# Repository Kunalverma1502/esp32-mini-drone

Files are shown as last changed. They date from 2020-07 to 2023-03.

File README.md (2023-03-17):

# ESP-32 Drone 🛸
ESP-32 Drone is an open-source light weight and compact drone with extended IO's for adding multiple sensors.

# Hardware ⚙️

## Designs

### 3D CAD
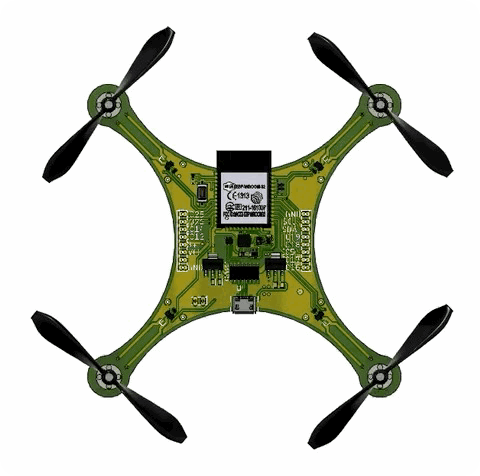
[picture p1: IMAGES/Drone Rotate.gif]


## Features

 - 
 - 
 - 
 - 
 - 
 <br/>
  <br/>
   <br/>
    <br/>
     <br/>
  <br/>
   <br/>
    <br/>
     <br/>
  <br/>
   <br/>
    <br/>
     <br/>
  <br/>
   <br/>
    <br/>

<p align="right">
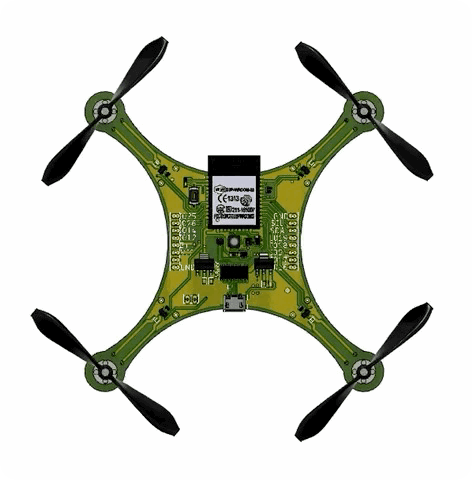
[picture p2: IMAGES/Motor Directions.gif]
  
</p>

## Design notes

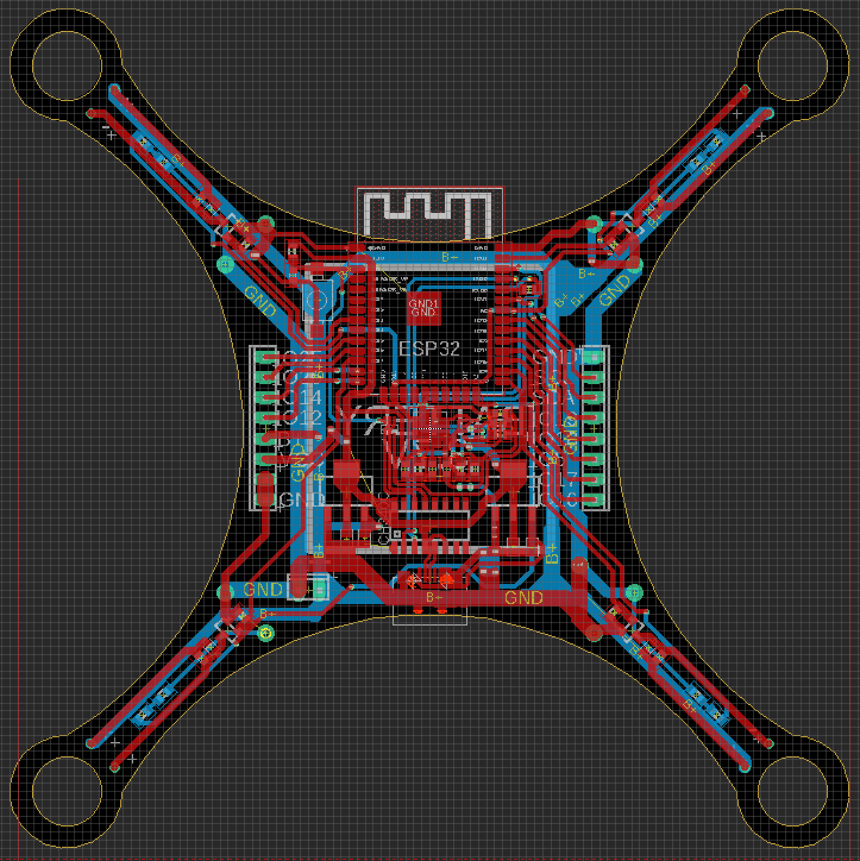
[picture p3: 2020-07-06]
SCHEMATIC/PCB VIEW.png

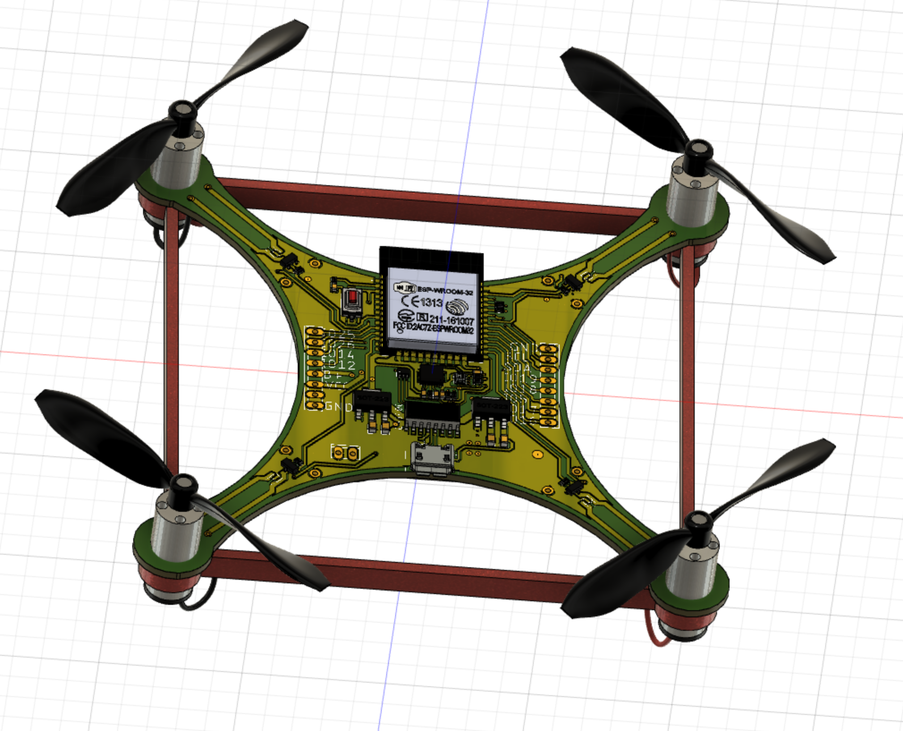
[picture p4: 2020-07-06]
CAD MODEL/IMAGES/DRONE1.png

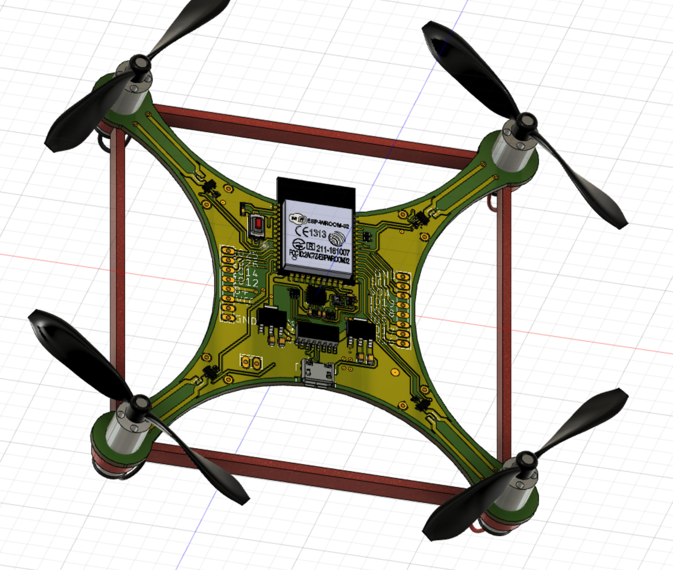
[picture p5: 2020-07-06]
CAD MODEL/IMAGES/DRONE2.png

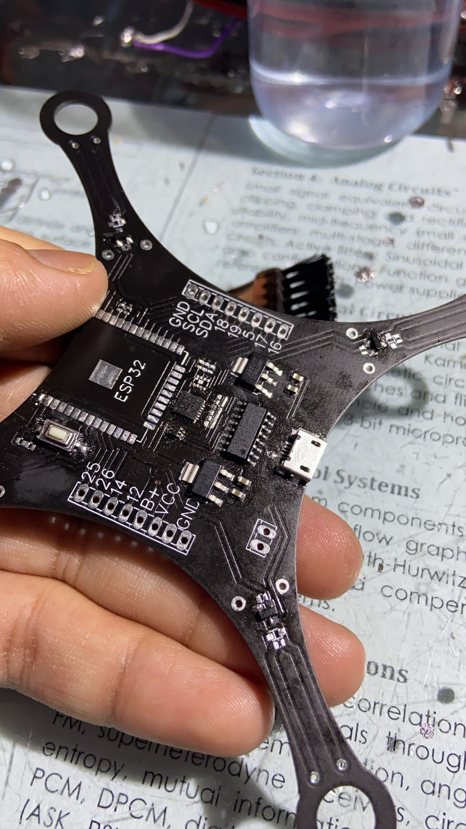
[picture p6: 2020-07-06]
IMAGES/31043101-7F11-4E39-B8AF-DA0E64A641B5.JPG

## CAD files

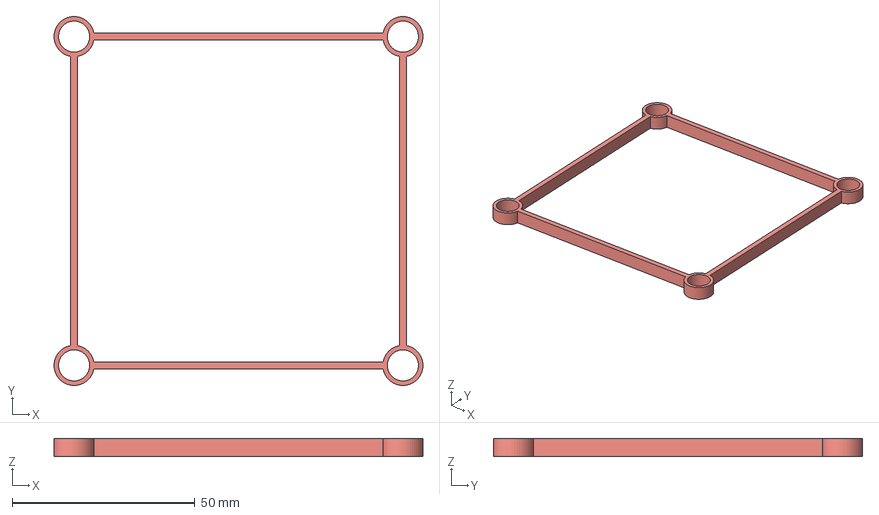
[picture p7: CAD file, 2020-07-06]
Drone Frame/DRONE_FRAME.step
101.0 x 101.0 x 5.00 mm

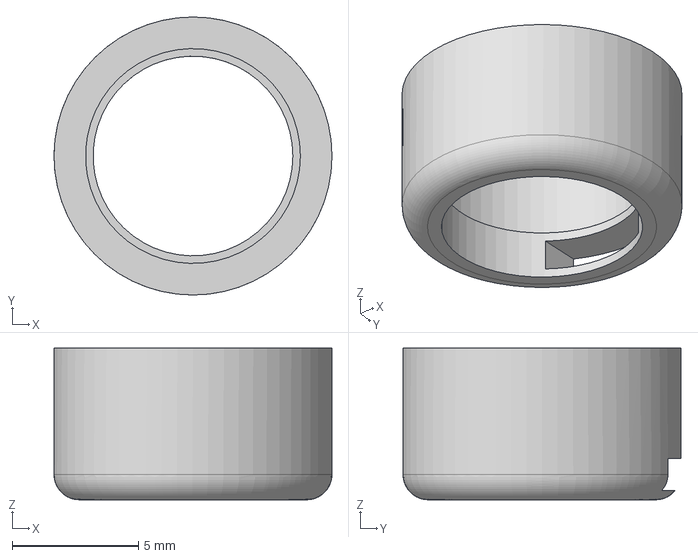
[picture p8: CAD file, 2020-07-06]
Motor Cover/MOTOR_COVER.step
11.0 x 11.0 x 6.00 mm

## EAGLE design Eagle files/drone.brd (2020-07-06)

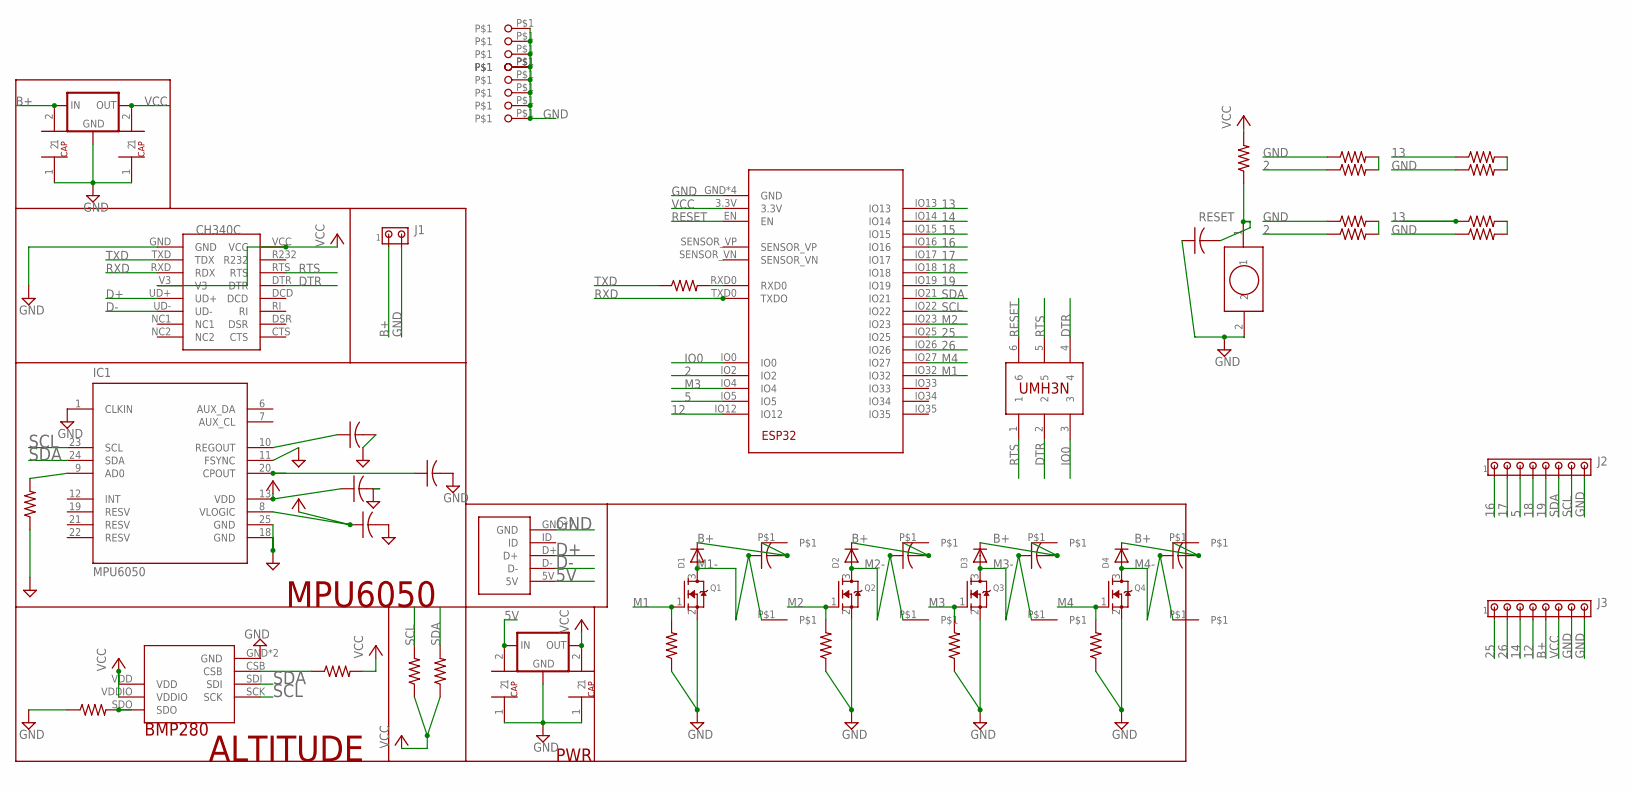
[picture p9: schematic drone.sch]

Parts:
D1, D2, D3, D4: DIODESOD-323F; SOD-323F
IC1: MPU6050; QFN50P400X400X95-25T265X275N
IC2, IC3: SELF_VREG3.3MP; SOT223
J1: MTA02-100; 10X02MTA
J2, J3: MTA08-100; 10X08MTA
Q1, Q2, Q3, Q4: MOSFET-NREFLOW; SOT23
U1: ESP32; MODULE_ESP-WROOM-32
U$1: MICROUSB; USB
U$2: CH340C; SOIC16
U$3: BMP280
U$4, U$5, U$7, U$11, U$12, U$16, U$20, U$21, U$22, U$23, U$30, U$32, U$33, U$34, U$35, U$36, U$37, U$38, U$39: R-US_R0603; R0603
U$6, U$8, U$9, U$10, U$24, U$25, U$26, U$27, U$31: C-USC0603; C0603
U$13, U$14, U$18, U$19: SELF_CAP_0603SELF_CAP_0805; SELF_CAP_0805
U$28: UMH3N
U$29: SELF_PUSHBUTTON
U$40, U$41, U$42, U$43, U$44, U$45, U$46, U$47: SELF_PINOUTS; PINOUTS
U$48, U$49, U$50, U$51, U$52, U$53, U$54, U$55, U$56: SELF_PIN2; PIN2

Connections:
2: U1.IO2, U$33.1, U$39.1
5: J2.3, U1.IO5
5V: IC2.VIN (IN), U$1.5V, U$13.2
12: J3.4, U1.IO12
13: U1.IO13, U$34.1, U$36.1
14: J3.3, U1.IO14
15: U1.IO15
16: J2.1, U1.IO16
17: J2.2, U1.IO17
18: J2.4, U1.IO18
19: J2.5, U1.IO19
25: J3.1, U1.IO25
26: J3.2, U1.IO26
B+: D1.C, D2.C, D3.C, D4.C, IC3.VIN (IN), J1.1, J3.5, U$19.2, U$24.2, U$25.2, U$26.2, U$27.2, U$40.P$1, U$42.P$1, U$44.P$1, U$46.P$1
D+: U$1.D+, U$2.UD+
D-: U$1.D-, U$2.UD-
DTR: U$2.DTR, U$28.2, U$28.4
GND: IC1.1 (CLKIN), IC1.11 (FSYNC), IC1.18 (GND), IC1.25 (GND), IC2.GND, IC3.GND, J1.2, J2.8, J3.7, J3.8, Q1.2 (S), Q2.2 (S), Q3.2 (S), Q4.2 (S), U1.GND, U1.GND1 (GND), U1.GND2 (GND), U1.GND3 (GND), U$1.GND, U$1.GND1 (GND), U$1.GND2 (GND), U$1.GND3 (GND), U$1.GND4 (GND), U$1.GND5 (GND), U$1.GND6 (GND), U$2.GND, U$3.GND, U$3.GND1 (GND), U$5.1, U$6.2, U$7.1, U$8.2, U$9.2, U$10.2, U$13.1, U$14.1, U$18.1, U$19.1, U$20.1, U$21.1, U$22.1, U$23.1, U$29.2, U$31.1, U$32.1, U$35.1, U$37.1, U$38.1, U$48.P$1, U$49.P$1, U$50.P$1, U$51.P$1, U$52.P$1, U$53.P$1, U$54.P$1, U$55.P$1, U$56.P$1
IO0: U1.IO0, U$28.3
M1: Q1.1 (G), U1.IO32, U$20.2
M1-: D1.A, Q1.3 (D), U$24.1, U$41.P$1
M2: Q2.1 (G), U1.IO23, U$21.2
M2-: D2.A, Q2.3 (D), U$26.1, U$43.P$1
M3: Q3.1 (G), U1.IO4, U$22.2
M3-: D3.A, Q3.3 (D), U$27.1, U$45.P$1
M4: Q4.1 (G), U1.IO27, U$23.2
M4-: D4.A, Q4.3 (D), U$25.1, U$47.P$1
unnamed: U$32.2, U$33.2
unnamed: U$38.2, U$39.2
unnamed: U$34.2, U$35.2
unnamed: U$36.2, U$37.2
unnamed: U$3.SDO, U$5.2
unnamed: U$3.CSB, U$4.1
unnamed: IC1.9 (AD0), U$7.2
unnamed: IC1.10 (REGOUT), U$8.1
unnamed: IC1.20 (CPOUT), U$10.1
unnamed: U1.RXD0, U$16.2
RESET: U1.EN, U$28.6, U$29.1, U$30.1, U$31.2
RTS: U$2.RTS, U$28.1, U$28.5
RXD: U1.TXD0 (TXDO), U$2.RXD (RDX)
SCL: IC1.23 (SCL), J2.7, U1.IO22, U$3.SCK, U$11.2
SDA: IC1.24 (SDA), J2.6, U1.IO21, U$3.SDI, U$12.2
TXD: U$2.TXD (TDX), U$16.1
VCC: IC1.8 (VLOGIC), IC1.13 (VDD), IC2.VOUT (OUT), IC2.VOUT1 (OUT), IC3.VOUT (OUT), IC3.VOUT1 (OUT), J3.6, U1.3.3V, U$2.V3, U$2.VCC, U$3.VDD, U$3.VDDIO, U$4.2, U$6.1, U$9.1, U$11.1, U$12.1, U$14.2, U$18.2, U$30.2

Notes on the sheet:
ALTITUDE
MPU6050
PWR

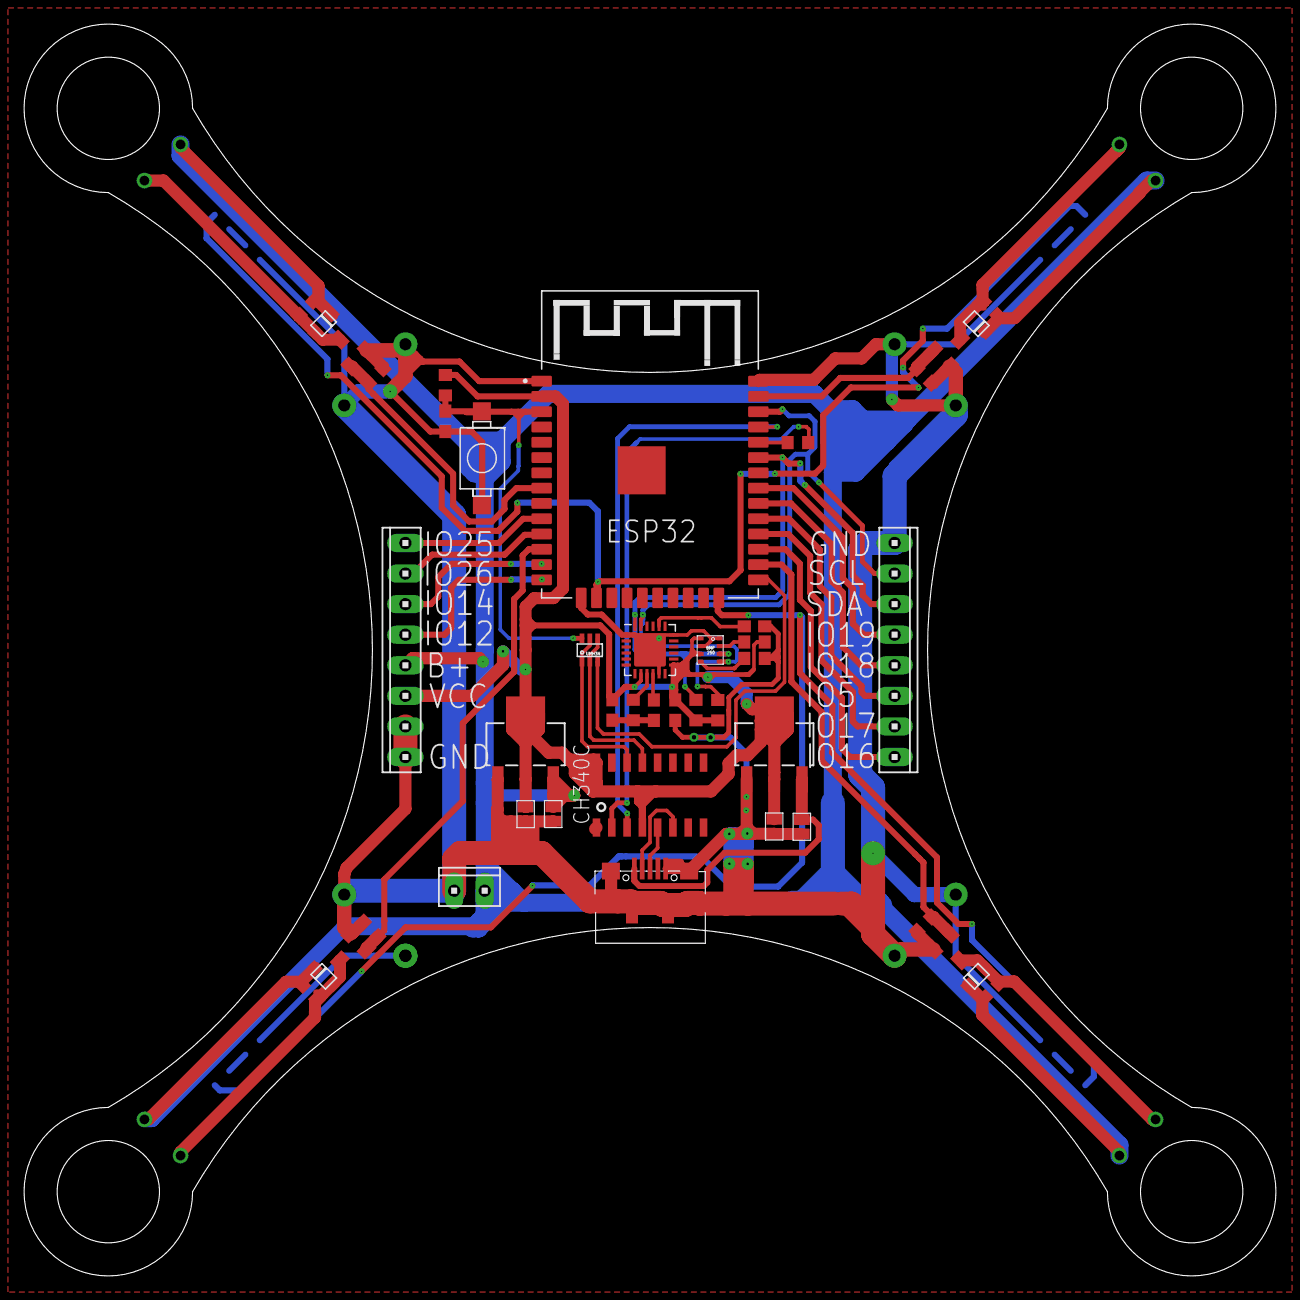
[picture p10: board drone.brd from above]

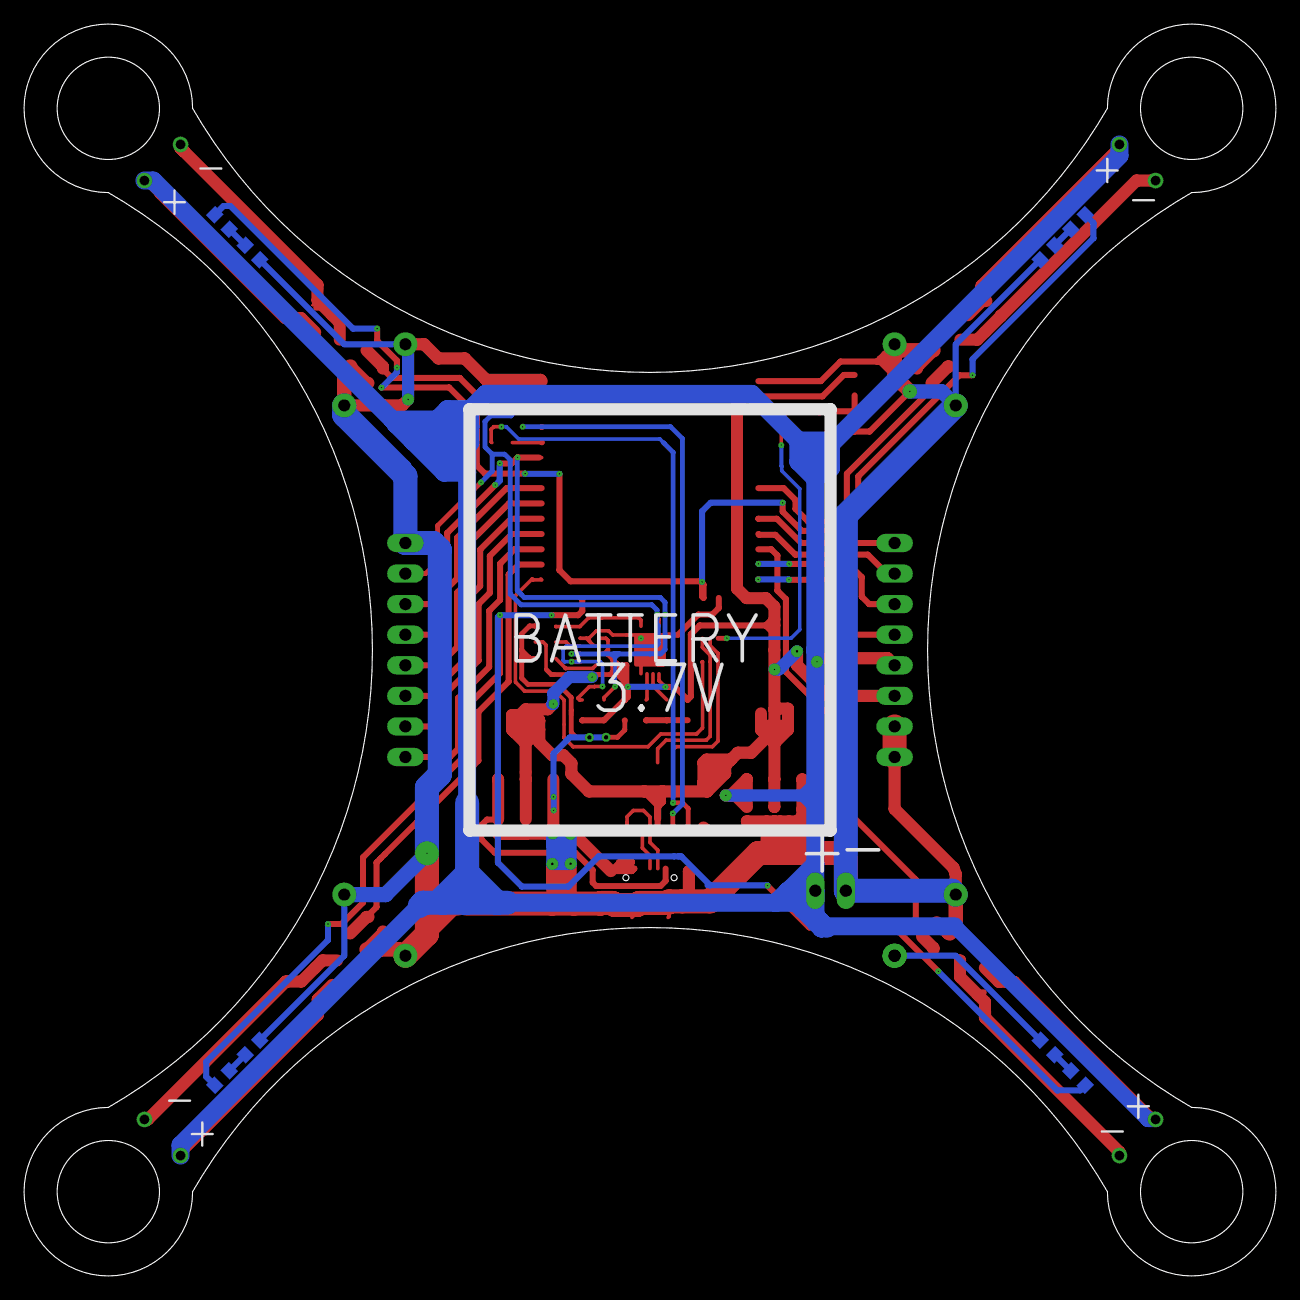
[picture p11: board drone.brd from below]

Board: 2 copper layers, 104.0 x 104.0 mm, 69 parts (8 on the bottom side), 43 nets.

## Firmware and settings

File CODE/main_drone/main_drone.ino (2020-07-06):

#include "PS3.h"
#include "MPU6050.h"



float roll_sample_angle = 0.0, pitch_sample_angle = 0.0, yaw_sample_angle = 0.0;
float roll_angle = 0.0, pitch_angle = 0.0, yaw_angle = 0.0;

float roll_sample_gyro = 0.0, pitch_sample_gyro = 0.0, yaw_sample_gyro = 0.0;
float roll_gyro = 0.0, pitch_gyro = 0.0, yaw_gyro = 0.0;


float esc_1, esc_2, esc_3, esc_4;
int throttle = 127;
int roll = 127;
int pitch = 127;
int yaw = 127;
bool drone = false;


float angle_roll_input = 0, angle_pitch_input = 0, angle_yaw_input = 0;
float pid_error_temp;
float pid_i_mem_roll, pid_roll_setpoint = 0, gyro_roll_input, pid_output_roll, pid_last_roll_d_error;
float pid_i_mem_pitch, pid_pitch_setpoint = 0, gyro_pitch_input, pid_output_pitch, pid_last_pitch_d_error;
float pid_i_mem_yaw, pid_yaw_setpoint = 0, gyro_yaw_input, pid_output_yaw, pid_last_yaw_d_error;

///////////////////////////////////////////////////////////////////////////////////////////////////////////////////////////////////////
//PID gain and limit settings
///////////////////////////////////////////////////////////////////////////////////////////////////////////////////////////////////////

float pid_p_gain_roll = 0.15;               //Gain setting for the roll P-controller
float pid_i_gain_roll = 0;              //Gain setting for the roll I-controller
float pid_d_gain_roll =  0;              //Gain setting for the roll D-controller
int pid_max_roll = 50;                    //Maximum output of the PID-controller (+/-)

float pid_p_gain_pitch = 0.2;  //Gain setting for the pitch P-controller.
float pid_i_gain_pitch = pid_i_gain_roll;  //Gain setting for the pitch I-controller.
float pid_d_gain_pitch = pid_d_gain_roll;  //Gain setting for the pitch D-controller.
int pid_max_pitch = pid_max_roll;          //Maximum output of the PID-controller (+/-)

float pid_p_gain_yaw = 0.2;                //Gain setting for the pitch P-controller. //4.0
float pid_i_gain_yaw = 0;               //Gain setting for the pitch I-controller. //0.02
float pid_d_gain_yaw = 0;                //Gain setting for the pitch D-controller.
int pid_max_yaw = 50;                     //Maximum output of the PID-controller (+/-)



void setup() {


  Serial.begin(115200);
  PS3_SETUP();
  MPU6050_SETUP();

  lights(1);

  for (int x = 0; x < 2000; x++) {
    mpu6050.update();
    roll_sample_angle +=  mpu6050.getAngleY();
    pitch_sample_angle +=  mpu6050.getAngleX();
    yaw_sample_angle += (mpu6050.getAngleZ() * -1);


    roll_sample_gyro +=  mpu6050.getGyroY();
    pitch_sample_gyro +=  mpu6050.getGyroX();
    yaw_sample_gyro +=  (mpu6050.getGyroZ() * -1);

  }

  roll_sample_angle /=  2000;
  pitch_sample_angle /= 2000;
  yaw_sample_angle /= 2000;

  roll_sample_gyro /=  2000;
  pitch_sample_gyro /=  2000;
  yaw_sample_gyro /=  2000;

  lights(0);

  Serial.println("MPU6050 calibrated");

//    Serial.println();
//  Serial.println();
//  delay(1000);
//
//  Serial.print(roll_sample_angle);
//  Serial.print("\t");
//  Serial.print(pitch_sample_angle);
//  Serial.print("\t");
//  Serial.println(yaw_sample_angle);
//  Serial.println();
//  Serial.println();
//  delay(1000);
//  
//
//  Serial.print(roll_sample_gyro);
//  Serial.print("\t");
//  Serial.print(pitch_sample_gyro);
//  Serial.print("\t");
//  Serial.println(yaw_sample_gyro);
//  delay(5000);
  

}
void calculate_pid() {
  //Roll calculations
  pid_error_temp = gyro_roll_input - pid_roll_setpoint;
  pid_i_mem_roll += pid_i_gain_roll * pid_error_temp;
  if (pid_i_mem_roll > pid_max_roll)pid_i_mem_roll = pid_max_roll;
  else if (pid_i_mem_roll < pid_max_roll * -1)pid_i_mem_roll = pid_max_roll * -1;

  pid_output_roll = pid_p_gain_roll * pid_error_temp + pid_i_mem_roll + pid_d_gain_roll * (pid_error_temp - pid_last_roll_d_error);
  if (pid_output_roll > pid_max_roll)pid_output_roll = pid_max_roll;
  else if (pid_output_roll < pid_max_roll * -1)pid_output_roll = pid_max_roll * -1;

  pid_last_roll_d_error = pid_error_temp;

  //Pitch calculations
  pid_error_temp = gyro_pitch_input - pid_pitch_setpoint;
  pid_i_mem_pitch += pid_i_gain_pitch * pid_error_temp;
  if (pid_i_mem_pitch > pid_max_pitch)pid_i_mem_pitch = pid_max_pitch;
  else if (pid_i_mem_pitch < pid_max_pitch * -1)pid_i_mem_pitch = pid_max_pitch * -1;

  pid_output_pitch = pid_p_gain_pitch * pid_error_temp + pid_i_mem_pitch + pid_d_gain_pitch * (pid_error_temp - pid_last_pitch_d_error);
  if (pid_output_pitch > pid_max_pitch)pid_output_pitch = pid_max_pitch;
  else if (pid_output_pitch < pid_max_pitch * -1)pid_output_pitch = pid_max_pitch * -1;

  pid_last_pitch_d_error = pid_error_temp;

  //Yaw calculations
  pid_error_temp = gyro_yaw_input - pid_yaw_setpoint;
  pid_i_mem_yaw += pid_i_gain_yaw * pid_error_temp;
  if (pid_i_mem_yaw > pid_max_yaw)pid_i_mem_yaw = pid_max_yaw;
  else if (pid_i_mem_yaw < pid_max_yaw * -1)pid_i_mem_yaw = pid_max_yaw * -1;

  pid_output_yaw = pid_p_gain_yaw * pid_error_temp + pid_i_mem_yaw + pid_d_gain_yaw * (pid_error_temp - pid_last_yaw_d_error);
  if (pid_output_yaw > pid_max_yaw)pid_output_yaw = pid_max_yaw;
  else if (pid_output_yaw < pid_max_yaw * -1)pid_output_yaw = pid_max_yaw * -1;

  pid_last_yaw_d_error = pid_error_temp;
}

void loop() {

  ///////////////////////////////////////////////////////////////////////////////////////////////////////////////////////////////////////
  //ANGLE & GYRO INPUTS
  ///////////////////////////////////////////////////////////////////////////////////////////////////////////////////////////////////////

  mpu6050.update();

  roll_angle = mpu6050.getAngleY() - roll_sample_angle;
  pitch_angle = mpu6050.getAngleX() - pitch_sample_angle;
  yaw_angle = (mpu6050.getAngleZ() * -1) - yaw_sample_angle;

  roll_gyro =  mpu6050.getGyroY() - roll_sample_gyro;
  pitch_gyro =  mpu6050.getGyroX() - pitch_sample_gyro;
  yaw_gyro =  (mpu6050.getGyroZ() * -1) - yaw_sample_gyro;

  ///////////////////////////////////////////////////////////////////////////////////////////////////////////////////////////////////////
  //COMPLIMENTARY FILTER 100 = 70(of previous value) + 30(of updated value)
  ///////////////////////////////////////////////////////////////////////////////////////////////////////////////////////////////////////

  angle_roll_input = (angle_roll_input * 0.94) + ((roll_angle) * 0.06);     //roll angle
  angle_pitch_input = (angle_pitch_input * 0.94) + ((pitch_angle) * 0.06);  //pitch angle
  angle_yaw_input = (angle_yaw_input * 0.94) + ((yaw_angle) * 0.06);        //yaw angle

  gyro_roll_input = (gyro_roll_input * 0.7) + ((roll_gyro) * 0.3)  ;     //roll gyro
  gyro_pitch_input = (gyro_pitch_input * 0.7) + ((pitch_gyro) * 0.3);    //pitch gyro
  gyro_yaw_input = (gyro_yaw_input * 0.7) + ((yaw_gyro) * 0.3);          //yaw gyro



  ///////////////////////////////////////////////////////////////////////////////////////////////////////////////////////////////////////
  //PS3 INPUTS
  ///////////////////////////////////////////////////////////////////////////////////////////////////////////////////////////////////////

  throttle = Ps3.data.analog.stick.ly;
  throttle = map(throttle, 127, -128, 0, 255);

  pid_roll_setpoint = 0;
  roll = Ps3.data.analog.stick.rx;
  pid_roll_setpoint = map(roll, 127, -128, 80, -80);
  pid_roll_setpoint -= angle_roll_input;
  pid_roll_setpoint /= 2;



  pid_pitch_setpoint = 0;
  pitch = Ps3.data.analog.stick.ry;
  pid_pitch_setpoint = map(pitch, 127, -128, 80, -80);
  pid_pitch_setpoint -= angle_pitch_input;
  pid_pitch_setpoint /= 2;

  pid_yaw_setpoint = 0;
  pid_yaw_setpoint -= angle_yaw_input;
  pid_yaw_setpoint /= 3.0;

  //  Serial.println(pid_roll_setpoint);
  //  Serial.print("\t");
  //  Serial.println(pid_pitch_setpoint);
  //  Serial.print("\t");
  //  Serial.println(pid_yaw_setpoint);

  //  Serial.print(gyro_roll_input);
  //  Serial.print("\t");
  //  Serial.print(gyro_pitch_input);
  //  Serial.print("\t");
  //  Serial.println(gyro_yaw_input);




  if ( Ps3.data.button.cross)
  { drone = true;


    //Reset the PID controllers for a bumpless start.
    pid_i_mem_roll = 0;
    pid_last_roll_d_error = 0;
    pid_i_mem_pitch = 0;
    pid_last_pitch_d_error = 0;
    pid_i_mem_yaw = 0;
    pid_last_yaw_d_error = 0;
  }

  if (Ps3.data.button.triangle)
  {
    drone = false;
  }

  calculate_pid();



  if ( drone == true ) {


    lights(1);
    esc_2 = throttle - pid_output_pitch + pid_output_roll - pid_output_yaw; //Calculate the pulse for esc 1 (front-right - CCW)
    esc_3 = throttle + pid_output_pitch + pid_output_roll + pid_output_yaw; //Calculate the pulse for esc 2 (rear-right - CW)
    esc_4 = throttle + pid_output_pitch - pid_output_roll - pid_output_yaw; //Calculate the pulse for esc 3 (rear-left - CCW)
    esc_1 = throttle - pid_output_pitch - pid_output_roll + pid_output_yaw; //Calculate the pulse for esc 4 (front-left - CW)

    if (esc_1 < 10) esc_1 = 0;
    if (esc_2 < 10) esc_2 = 0;
    if (esc_3 < 10) esc_3 = 0;
    if (esc_4 < 10) esc_4 = 0;

    if (esc_1 > 255)esc_1 = 255;
    if (esc_2 > 255)esc_2 = 255;
    if (esc_3 > 255)esc_3 = 255;
    if (esc_4 > 255)esc_4 = 255;

//        Serial.print(esc_1);
//        Serial.print("\t");
//        Serial.print(esc_2);
//        Serial.print("\t");
//        Serial.print(esc_3);
//        Serial.print("\t");
//        Serial.println(esc_4);



    ledcWrite(ledChannel1, esc_1);
    ledcWrite(ledChannel2, esc_2);
    ledcWrite(ledChannel3, esc_3);
    ledcWrite(ledChannel4, esc_4);
  }
  else {
    lights(0);
    ledcWrite(ledChannel1, 0);
    ledcWrite(ledChannel2, 0);
    ledcWrite(ledChannel3, 0);
    ledcWrite(ledChannel4, 0);
  }



}

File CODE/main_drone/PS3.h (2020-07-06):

#include <Ps3Controller.h>

#define m1 32
#define m2 23
#define m3 4
#define m4 27
#define red 13
#define green 2

#define freq  5000
#define resolution   8
#define ledChannel1  0
#define ledChannel2  1
#define ledChannel3  2
#define ledChannel4  3


void PS3_SETUP()
{
  Ps3.begin("01:00:01:01:09:09");
  
  Serial.println("PS3 STARTED");


  ledcSetup(ledChannel1, freq, resolution);
  ledcSetup(ledChannel2, freq, resolution);
  ledcSetup(ledChannel3, freq, resolution);
  ledcSetup(ledChannel4, freq, resolution);

  ledcAttachPin(m1, ledChannel1);
  ledcAttachPin(m2, ledChannel2);
  ledcAttachPin(m3, ledChannel3);
  ledcAttachPin(m4, ledChannel4);

  pinMode(red, OUTPUT);
  pinMode(green, OUTPUT);
}

void lights(int a) {
  digitalWrite(red, a);
  digitalWrite(green, a);
}
